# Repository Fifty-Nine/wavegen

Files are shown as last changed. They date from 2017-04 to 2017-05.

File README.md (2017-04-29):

Introduction
============

This is an implementation of a USB-controlled Analog Devices AD9837-based 
function generator that can generate sine, triangle and square waves up to 
around 200 kHz or so, 1 MHz if the output filtering capacitor is removed
(although the quantization of the ADC starts to become apparent around
500 kHz).

Fully assembled Rev. 2 board

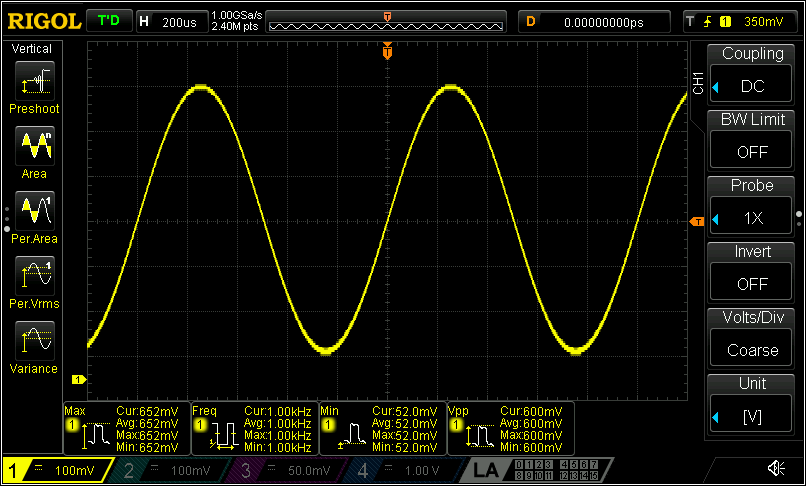
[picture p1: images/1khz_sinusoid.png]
Sample output


Connectors, Jumpers and Indicators
==================================

There are several off-board connectors, one jumper and three
LEDs.

| Reference | Purpose |
| --- | --- |
| J1 | Micro-B USB Connector |
| J2 | External clock input |
| J3 | Function generator output (0.6Vpp typical) |
| J4 | FTDI channel B breakout |
| TP1 | USB supply voltage (5V typical, 15V max) |
| TP2 | GND |
| TP3 | LD1117 output (3.3V nominal) |
| TP4 | Function generator output (0.6Vpp typical  |
| JP1 | Clock select jumper |
| D1 | LD1117 power indicator |
| D2 | Currently unused |
| D3 | Currently unused |

At some point I'll document the pinout for the J4 connector here.
Until then the pinout is available in the schematic.

Indicators D2 and D3 were originally intended as SPI TX/RX indicators, but
that was before I realized that the FT2232H only enables them for UART
communication (and also that the AD 9837 has no TX...). There's nothing
stopping the control software from using them for other purposes, although
the silkscreen on rev. 2 would be misleading.

Firmware
========

Because the design is based on the FTDI FT2232H, there's no firmware per se.
However, the control software looks for certain USB product and manufacturer
strings to differentiate the device from other FTDI devices. A template for
the FTDI 'FT_Prog' EEPROM programming software is provided in the `firmware/`
directory. The device should be programmed with this template before attempting
to use the control software.

Control Software
================

The control software is a work in progress, but the device can currently be
fully controlled via a provided software library. The library is written in
C++ and requires a compiler with C++11 support.

To build the library, you will need CMake and a suitable C++ compiler. On
linux, the build steps go something like this:

```
$ sudo apt-get install git build-essential cmake libftdi-dev
...
$ git clone git@github.com:Fifty-Nine/wavegen
...
$ cd wavegen/software
$ mkdir build
$ cd build
$ cmake ..
...
$ make
...
$ sudo make install
...
$
```

At this point, you can use the `wavegen-test` program to confirm that the device
is working. The test program initializes the device and repeatedly performs a
frequency sweep.

Future Work
===========

A GUI control interface would be nice to have. 

One major limitation of the current hardware is that it provides no output
amplitude control or amplification. At some point I would like to design
an amplification stage with automatic gain control. Rev 3 will allow
arbitrary waveform generation, so this will be mitigated somewhat.

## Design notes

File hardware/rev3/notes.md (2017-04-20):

Notes for a future rev3
=======================

- Stacking/nesting design.
- Replace VOUT capacitor with something much smaller to decrease attenuation at higher frequencies.
- ESD suppression on the USB lines.
- Shorten USB traces, try to get the impedance closer to the spec.
- Amplifier stage (w/AGC?)
- RCA jack?
- Microcontroller-based LCD UI?
- Multiple channels?
- ADC

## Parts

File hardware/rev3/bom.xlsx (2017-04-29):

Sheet: Sheet1
Id | Designator | Designation | Package | Quantity | Supplier and ref
1 | D1 | Green | LED_0805 | 1 | 350-2900-ND (https://www.digikey.com/products/en?keywords=350-2900-ND)
2 | J3;J5 | CONN_02X09 | Pin_Header_Straight_2x09_Pitch2.54mm | 2 | S2011EC-40-ND (https://www.digikey.com/products/en?keywords=S2011EC-40-ND)
3 | TP1 | VBUS | Test_Point_Keystone_5005-5009_Compact | 1 | 36-5009-ND (https://www.digikey.com/products/en?keywords=36-5009-ND)
4 | TP2 | +3.3V | Test_Point_Keystone_5005-5009_Compact | 1 | 36-5005-ND (https://www.digikey.com/products/en?keywords=36-5005-ND)
5 | TP3 | GND | Test_Point_Keystone_5005-5009_Compact | 1 | 36-5006-ND (https://www.digikey.com/products/en?keywords=36-5006-ND)
6 | U1 | LD1117S33TR | SOT-223 | 1 | 497-1242-1-ND (https://www.digikey.com/products/en/integrated-circuits-ics/pmic-voltage-regulators-linear/699?k=497-1242-1-ND)
7 | U2 | 93LCxxB | SOIC-8_3.9x4.9mm_Pitch1.27mm | 1 | 93LC46BT-I/SNCT-ND (https://www.digikey.com/products/en?keywords=93LC46BT-I%2FSNCT-ND)
8 | U3 | FT2232H | LQFP-64_10x10mm_Pitch0.5mm | 1 | 768-1024-1-ND (https://www.digikey.com/products/en?keywords=768-1024-1-ND)
9 | Y1 | 12MHz | Crystal_SMD_5032-2pin_5.0x3.2mm | 1 | 535-10634-1-ND (https://www.digikey.com/products/en?keywords=535-10634-1-ND)
10 | C1;C4;C6;C8-C15;C23-C25;C28;C30;C33;C35-C41;C44;C47 | 100n | C_0603_HandSoldering | 26 | 478-1239-1-ND (https://www.digikey.com/product-detail/en/avx-corporation/0603YC104KAT2A/478-1239-1-ND/564271)
11 | C2;C22;C29;C34;C42 | 10u | C_0603_HandSoldering | 5 | 478-8050-1-ND (https://www.digikey.com/product-detail/en/avx-corporation/0603ZD106MAT2A/478-8050-1-ND/3900666)
12 | C3;C5;C45 | 4.7u | C_0603_HandSoldering | 3 | 478-7943-1-ND (https://www.digikey.com/product-detail/en/avx-corporation/0603ZD475KAT2A/478-7943-1-ND/3881566)
13 | C7 | 3.3u | C_0603_HandSoldering | 1 | 490-6411-1-ND (https://www.digikey.com/product-detail/en/murata-electronics-north-america/GRM188R61A335KE15D/490-6411-1-ND/3845608)
14 | C16;C17 | 27p | C_0603_HandSoldering | 2 | 478-1168-1-ND (https://www.digikey.com/product-detail/en/avx-corporation/06035A270JAT2A/478-1168-1-ND/564200)
15 | C26;C32 | 0.8p | C_0603_HandSoldering | 2 | 478-6730-1-ND (https://www.digikey.com/product-detail/en/avx-corporation/ML03510R8AAT2A/478-6730-1-ND/2694244)
16 | C27;C31 | 2.8p | C_0603_HandSoldering | 2 | 478-3840-1-ND (https://www.digikey.com/product-detail/en/avx-corporation/06032U2R7BAT2A/478-3840-1-ND/1118502)
17 | C43;C46 | 1u | C_0603_HandSoldering | 2 | 478-5010-2-ND (https://www.digikey.com/product-detail/en/avx-corporation/0603YC105KAT2A/478-5010-2-ND/1888462)
18 | J2 | SMA | SMA_THT_Jack_Straight | 1 | A97594-ND (https://www.digikey.com/products/en?keywords=A97594-ND)
19 | J4;J6;J7 | SMA | Molex_SMA_Jack_Edge_Mount | 3 | WM5534-ND (https://www.digikey.com/product-detail/en/molex-llc/0732511150/WM5534-ND/1465156)
20 | L1;L2;L3;L4 | 800m | L_0603_HandSoldering | 4 | 490-5255-1-ND (https://www.digikey.com/product-detail/en/murata-electronics-north-america/BLM18KG221SN1D/490-5255-1-ND/1982778)
21 | R3;R4;R5 | 10k | R_0603_HandSoldering | 3 | P10KBZCT-ND (https://www.digikey.com/product-detail/en/panasonic-electronic-components/ERJ-PA3J103V/P10KBZCT-ND/5036237)
22 | R6 | 2.2k | R_0603_HandSoldering | 1 | P2.2KBZCT-ND (https://www.digikey.com/product-detail/en/panasonic-electronic-components/ERJ-PA3J222V/P2.2KBZCT-ND/5036284)
23 | R7;R13;R16;R17;R25;R29 | 4.7k | R_0603_HandSoldering | 6 | P4.7KBZCT-ND (https://www.digikey.com/product-detail/en/panasonic-electronic-components/ERJ-PA3J472V/P4.7KBZCT-ND/5036332)
24 | R8 | 12k | R_0603_HandSoldering | 1 | P12.0KHCT-ND (https://www.digikey.com/product-detail/en/panasonic-electronic-components/ERJ-3EKF1202V/P12.0KHCT-ND/1746728)
25 | R11 | 8.25k | R_0603_HandSoldering | 1 | P8.25KDBCT-ND (https://www.digikey.com/products/en/resistors/chip-resistor-surface-mount/52?k=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)
26 | R2;R12;R27 | 510 | R_0603_HandSoldering | 3 | P510BYCT-ND (https://www.digikey.com/products/en/resistors/chip-resistor-surface-mount/52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)
27 | R14;R23 | 1.5k | R_0603_HandSoldering | 2 | P1.5KBYCT-ND (https://www.digikey.com/product-detail/en/panasonic-electronic-components/ERJ-PA3F1501V/P1.5KBYCT-ND/5036135)
28 | R15;R19;R20;R22;R24 | 100 | R_0603_HandSoldering | 5 | P100BYCT-ND (https://www.digikey.com/product-detail/en/panasonic-electronic-components/ERJ-PA3F1000V/P100BYCT-ND/5036113)
29 | R18;R21 | 1k | R_0603_HandSoldering | 2 | P1.0KBYCT-ND (https://www.digikey.com/product-detail/en/panasonic-electronic-components/ERJ-PA3F1001V/P1.0KBYCT-ND/5036114)
30 | R26;R28 | 36k | R_0603_HandSoldering | 2 | P20459CT-ND (https://www.digikey.com/product-detail/en/panasonic-electronic-components/ERJ-PB3D3602V/P20459CT-ND/6214714)
31 | TP4 | TRIGGER | Test_Point_Keystone_5005-5009_Compact | 1 | 36-5122-ND (https://www.digikey.com/product-detail/en/keystone-electronics/5122/36-5122-ND/2170325)
32 | TP5 | VOUT+ | Test_Point_Keystone_5005-5009_Compact | 1 | 36-5005-ND (https://www.digikey.com/product-detail/en/keystone-electronics/5005/36-5005-ND/255329)
33 | TP6 | VOUT- | Test_Point_Keystone_5005-5009_Compact | 1 | 36-5007-ND (https://www.digikey.com/product-detail/en/keystone-electronics/5007/36-5007-ND/255331)
34 | TP7 | VOUT | Test_Point_Keystone_5005-5009_Compact | 1 | 36-5121-ND (https://www.digikey.com/product-detail/en/keystone-electronics/5121/36-5121-ND/2170324)
35 | U4 | LTC6409 | LTC6409-UDB | 1 | LTC6409CUDB#TRMPBFCT-ND (https://www.digikey.com/product-detail/en/linear-technology/LTC6409CUDB-TRMPBF/LTC6409CUDB-TRMPBFCT-ND/2404678)
36 | U5 | LTC6269 | LTC6269-10DFN | 1 | LTC6269HDD#PBF-ND (https://www.digikey.com/products/en/integrated-circuits-ics/linear-amplifiers-instrumentation-op-amps-buffer-amps/687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)
37 | U6 | AD9102 | AD9102-10LFCSP | 1 | AD9102BCPZ-ND (https://www.digikey.com/product-detail/en/analog-devices-inc/AD9102BCPZ/AD9102BCPZ-ND/3874219)
38 | X1 | DSC1123 | 3225XO | 1 | 576-4649-ND (https://www.digikey.com/products/en/crystals-oscillators-resonators/oscillators/172?k=dsc1123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)
39 | R30 | 18k | R_0603_HandSoldering | 1 | P20424CT-ND (https://www.digikey.com/product-detail/en/panasonic-electronic-components/ERJ-PB3D1802V/P20424CT-ND/6214679)
40 | J1 | USB_B | USB_Micro-B-circular | 1 | 609-4618-1-ND (https://www.digikey.com/product-detail/en/amphenol-fci/10118194-0001LF/609-4618-1-ND/2785382)
41 | JP1 | USB_PWR | Pin_Header_Straight_1x02_Pitch2.54mm | 1
42 | C18;C19;C20;C21 | DNP | C_0603_HandSoldering | 4
43 | R1;R9;R10 | DNP | R_0603_HandSoldering | 3
 |  |  |  | 97

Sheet: Sheet2
Quantity | Supplier and ref | Designator
1 | 350-2900-ND | D1
2 | S2011EC-40-ND | J3;J5
1 | 36-5009-ND | TP1
1 | 36-5005-ND | TP2
1 | 36-5006-ND | TP3
1 | 497-1242-1-ND | U1
1 | 93LC46BT-I/SNCT-ND | U2
1 | 768-1024-1-ND | U3
1 | 535-10634-1-ND | Y1
26 | 478-1239-1-ND | C1;C4;C6;C8-C15;C23-C25;C28;C30;C33;C35-C41;C44;C47
5 | 478-8050-1-ND | C2;C22;C29;C34;C42
3 | 478-7943-1-ND | C3;C5;C45
1 | 490-6411-1-ND | C7
2 | 478-1168-1-ND | C16;C17
2 | 478-6730-1-ND | C26;C32
2 | 478-3840-1-ND | C27;C31
2 | 478-5010-2-ND | C43;C46
1 | A97594-ND | J2
3 | WM5534-ND | J4;J6;J7
4 | 490-5255-1-ND | L1;L2;L3;L4
3 | P10KBZCT-ND | R3;R4;R5
1 | P2.2KBZCT-ND | R6
6 | P4.7KBZCT-ND | R7;R13;R16;R17;R25;R29
1 | P12.0KHCT-ND | R8
1 | P8.25KDBCT-ND | R11
3 | P510BYCT-ND | R2;R12;R27
2 | P1.5KBYCT-ND | R14;R23
5 | P100BYCT-ND | R15;R19;R20;R22;R24
2 | P1.0KBYCT-ND | R18;R21
2 | P20459CT-ND | R26;R28
1 | 36-5122-ND | TP4
1 | 36-5005-ND | TP5
1 | 36-5007-ND | TP6
1 | 36-5121-ND | TP7
1 | LTC6409CUDB#TRMPBFCT-ND | U4
1 | LTC6269HDD#PBF-ND | U5
1 | AD9102BCPZ-ND | U6
1 | 576-4649-ND | X1
1 | P20424CT-ND | R30
1 | 609-4618-1-ND | J1
1 | 0 | JP1
4 | 0 | C18;C19;C20;C21
3 | 0 | R1;R9;R10

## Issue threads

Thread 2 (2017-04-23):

Find some way to limit square wave output power

Fifty-Nine, 2017-04-23:
When outputting square waves, the AD9837 produces a signal at 3.3Vpp (~17 dBm with 50 ohm impedance), but triangle and sinusoids are around 600 mV (~0 dBm). Ideally the signal levels for square waves would be around the same power (or perhaps voltage levels) as the others.

Fifty-Nine, 2017-05-02:
On further reflection, I don't think this is that critical of an issue. It's not ideal, but without a hardware change I don't know that there's any way to fix it, and in most applications it won't be a problem.

Closed 2017-05-02.

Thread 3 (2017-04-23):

Missing ground connection on oscillator Y1

Fifty-Nine, 2017-04-23:
The decoupling caps on Y1 (12 MHz oscillator for the FTDI chip) are missing a connection to ground.

This can be worked around by using a small jumper to connect the capacitors' ground pad to the nearby bypass capacitors C19 and C20.

This is fixed in rev2.

Closed 2017-04-25.

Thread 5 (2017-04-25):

Python bindings should implement `__del__`

Fifty-Nine, 2017-04-25:
Currently when a `pywavegen.device` instance is destroyed, we don't actually delete the global instance. We should add a binding for `__del__` that calls 'reset' on the global shared pointer. We should also double check that this actually has the intended result of releasing the underlying resources.

Closed 2017-04-26.

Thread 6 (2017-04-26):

Add differential to single-ended stage to output amp

Fifty-Nine, 2017-04-26:
I've added another stage to the output amplifier to convert the differential signal into a single ended one, but haven't added it to the actual schematic yet.

Because the amplifiers are a little power hungry, I think we'll need to make use of their shutdown pins, which isn't reflected on the LTSpice schematic.

Closed 2017-05-02.

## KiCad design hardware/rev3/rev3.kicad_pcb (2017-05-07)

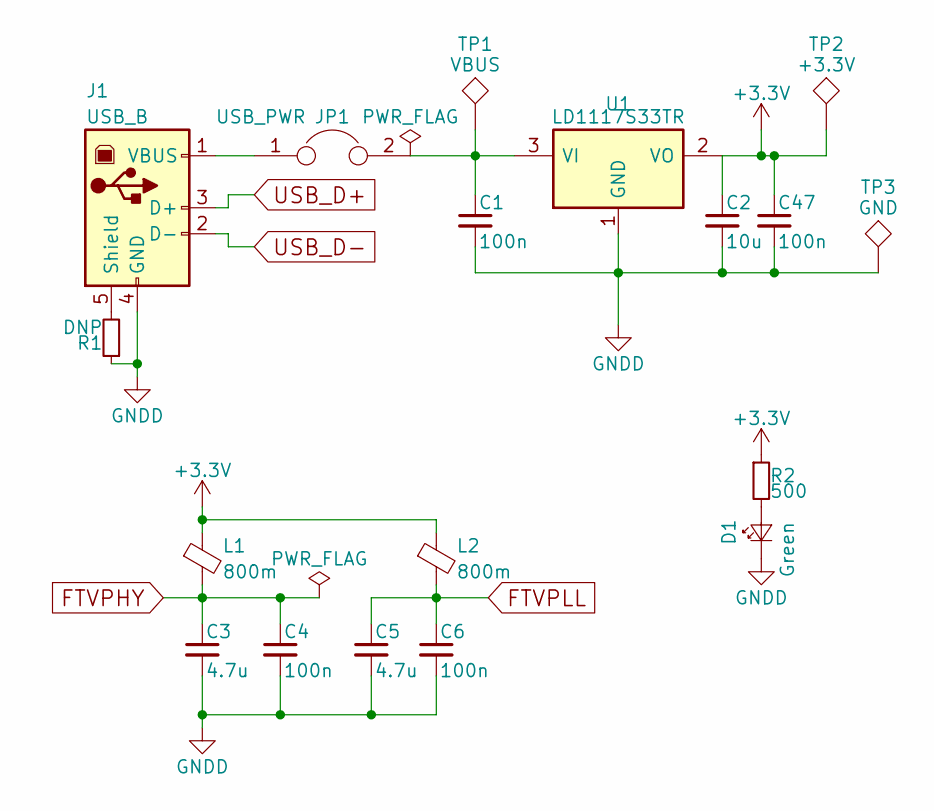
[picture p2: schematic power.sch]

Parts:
C1, C4, C6, C47: 100n; C_0603_HandSoldering; DigiKey 478-1395-1-ND
C2: 10u; C_0603_HandSoldering; DigiKey 478-10568-1-ND
C3, C5: 4.7u; C_0603_HandSoldering; DigiKey 478-1415-1-ND
D1: Green; LED_0805; DigiKey 350-2900-ND
J1: USB_B; USB_Micro-B-circular; DigiKey 609-4618-1-ND
JP1: USB_PWR; Pin_Header_Straight_1x02_Pitch2.54mm
L1, L2: 800m; L_0603_HandSoldering; DigiKey 490-1054-1-ND
R1: DNP; R_0603_HandSoldering; DigiKey DNP
R2: 500; R_0603_HandSoldering; DigiKey P470ADCT-ND
TP1: VBUS; Test_Point_Keystone_5005-5009_Compact; DigiKey 36-5009-ND
TP2: +3.3V; Test_Point_Keystone_5005-5009_Compact; DigiKey 36-5005-ND
TP3: GND; Test_Point_Keystone_5005-5009_Compact; DigiKey 36-5006-ND
U1: LD1117S33TR; SOT-223; DigiKey 497-1242-1-ND

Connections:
+3V3: C2.1, C47.1, L1.1, L2.1, R2.1, TP2.1, U1.2 (VO); also elsewhere on the board
FTVPHY: C3.1, C4.1, L1.2; also elsewhere on the board
FTVPLL: C5.1, C6.1, L2.2; also elsewhere on the board
GNDA: C1.2, C2.2, C3.2, C4.2, C5.2, C6.2, C47.2, D1.1 (K), J1.4 (GND), R1.1, TP3.1, U1.1 (GND); also elsewhere on the board
unnamed: C1.1, JP1.2, TP1.1, U1.3 (VI)
unnamed: D1.2 (A), R2.2
unnamed: J1.1 (VBUS), JP1.1
unnamed: J1.5 (Shield), R1.2
USB_D+: J1.3 (D+); also elsewhere on the board
USB_D-: J1.2 (D-); also elsewhere on the board

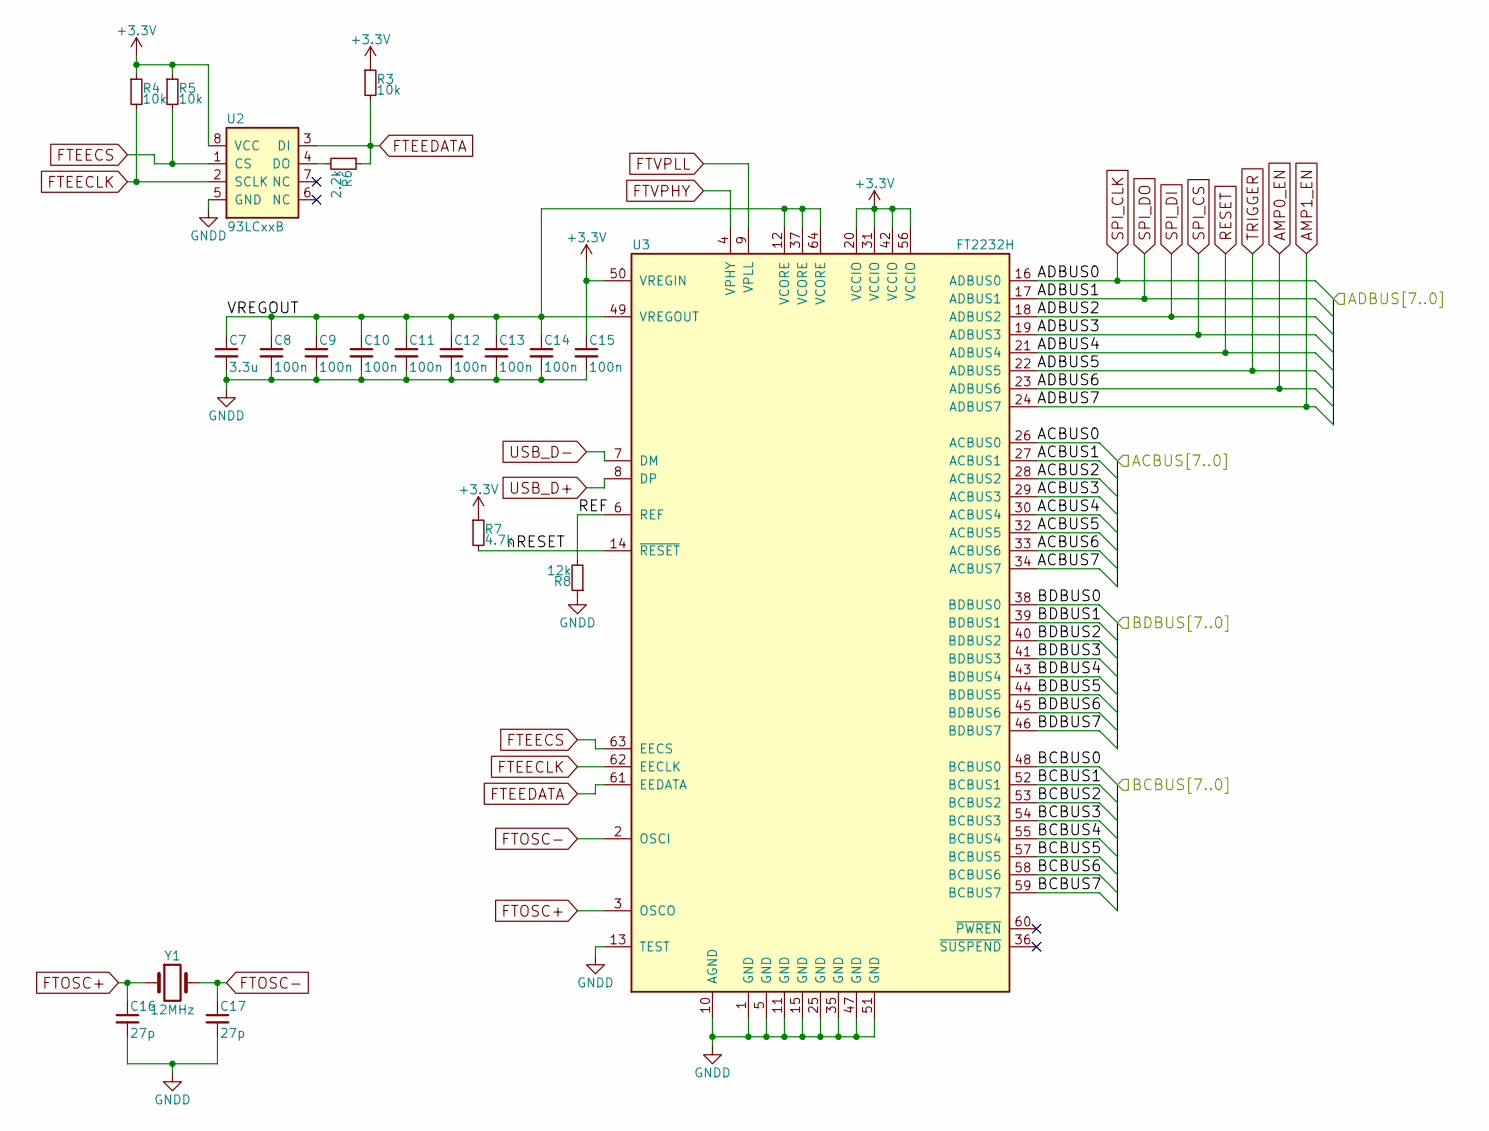
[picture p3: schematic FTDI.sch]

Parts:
C7: 3.3u; C_0805; DigiKey 478-1414-1-ND
C8, C9, C10, C11, C12, C13, C14, C15: 100n; C_0805; DigiKey 478-1395-1-ND
C16, C17: 27p; C_0805; DigiKey 478-10518-1-ND
R3, R4, R5: 10k; R_0805; DigiKey P10KADCT-ND
R6: 2.2k; R_0805; DigiKey P2.2KADCT-ND
R7: 4.7k; R_0805; DigiKey P1.0KADCT-ND
R8: 12k; R_0805; DigiKey P12KADCT-ND
U2: 93LCxxB; SOIC-8_3.9x4.9mm_Pitch1.27mm; DigiKey 93LC46B/SN-ND
U3: FT2232H; LQFP-64_10x10mm_Pitch0.5mm
Y1: 12MHz; Crystal_SMD_5032-2pin_5.0x3.2mm; DigiKey 535-10634-1-ND

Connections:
+3V3: C15.1, R3.1, R4.1, R5.1, R7.1, U2.8 (VCC), U3.20 (VCCIO), U3.31 (VCCIO), U3.42 (VCCIO), U3.50 (VREGIN), U3.56 (VCCIO); also elsewhere on the board
/Connectors/ACBUS0: U3.26 (ACBUS0); also elsewhere on the board
/Connectors/ACBUS1: U3.27 (ACBUS1); also elsewhere on the board
/Connectors/ACBUS2: U3.28 (ACBUS2); also elsewhere on the board
/Connectors/ACBUS3: U3.29 (ACBUS3); also elsewhere on the board
/Connectors/ACBUS4: U3.30 (ACBUS4); also elsewhere on the board
/Connectors/ACBUS5: U3.32 (ACBUS5); also elsewhere on the board
/Connectors/ACBUS6: U3.33 (ACBUS6); also elsewhere on the board
/Connectors/ACBUS7: U3.34 (ACBUS7); also elsewhere on the board
/Connectors/BCBUS0: U3.48 (BCBUS0); also elsewhere on the board
/Connectors/BCBUS1: U3.52 (BCBUS1); also elsewhere on the board
/Connectors/BCBUS2: U3.53 (BCBUS2); also elsewhere on the board
/Connectors/BCBUS3: U3.54 (BCBUS3); also elsewhere on the board
/Connectors/BCBUS4: U3.55 (BCBUS4); also elsewhere on the board
/Connectors/BCBUS5: U3.57 (BCBUS5); also elsewhere on the board
/Connectors/BCBUS6: U3.58 (BCBUS6); also elsewhere on the board
/Connectors/BCBUS7: U3.59 (BCBUS7); also elsewhere on the board
/Connectors/BDBUS0: U3.38 (BDBUS0); also elsewhere on the board
/Connectors/BDBUS1: U3.39 (BDBUS1); also elsewhere on the board
/Connectors/BDBUS2: U3.40 (BDBUS2); also elsewhere on the board
/Connectors/BDBUS3: U3.41 (BDBUS3); also elsewhere on the board
/Connectors/BDBUS4: U3.43 (BDBUS4); also elsewhere on the board
/Connectors/BDBUS5: U3.44 (BDBUS5); also elsewhere on the board
/Connectors/BDBUS6: U3.45 (BDBUS6); also elsewhere on the board
/Connectors/BDBUS7: U3.46 (BDBUS7); also elsewhere on the board
/FTDI/REF: R8.2, U3.6 (REF)
/FTDI/VREGOUT: C7.1, C8.1, C9.1, C10.1, C11.1, C12.1, C13.1, C14.1, U3.12 (VCORE), U3.37 (VCORE), U3.49 (VREGOUT), U3.64 (VCORE)
/FTDI/nRESET: R7.2, U3.14 (~RESET)
AMP0_EN: U3.23 (ADBUS6); also elsewhere on the board
AMP1_EN: U3.24 (ADBUS7); also elsewhere on the board
FTEECLK: R4.2, U2.2 (SCLK), U3.62 (EECLK)
FTEECS: R5.2, U2.1 (CS), U3.63 (EECS)
FTEEDATA: R3.2, R6.1, U2.3 (DI), U3.61 (EEDATA)
FTOSC+: C16.1, U3.3 (OSCO), Y1.1
FTOSC-: C17.1, U3.2 (OSCI), Y1.2
FTVPHY: U3.4 (VPHY); also elsewhere on the board
FTVPLL: U3.9 (VPLL); also elsewhere on the board
GNDA: C7.2, C8.2, C9.2, C10.2, C11.2, C12.2, C13.2, C14.2, C15.2, C16.2, C17.2, R8.1, U2.5 (GND), U3.1 (GND), U3.5 (GND), U3.10 (AGND), U3.11 (GND), U3.13 (TEST), U3.15 (GND), U3.25 (GND), U3.35 (GND), U3.47 (GND), U3.51 (GND); also elsewhere on the board
unnamed: R6.2, U2.4 (DO)
RESET: U3.21 (ADBUS4); also elsewhere on the board
SPI_CLK: U3.16 (ADBUS0); also elsewhere on the board
SPI_CS: U3.19 (ADBUS3); also elsewhere on the board
SPI_DI: U3.18 (ADBUS2); also elsewhere on the board
SPI_DO: U3.17 (ADBUS1); also elsewhere on the board
TRIGGER: U3.22 (ADBUS5); also elsewhere on the board
USB_D+: U3.8 (DP); also elsewhere on the board
USB_D-: U3.7 (DM); also elsewhere on the board

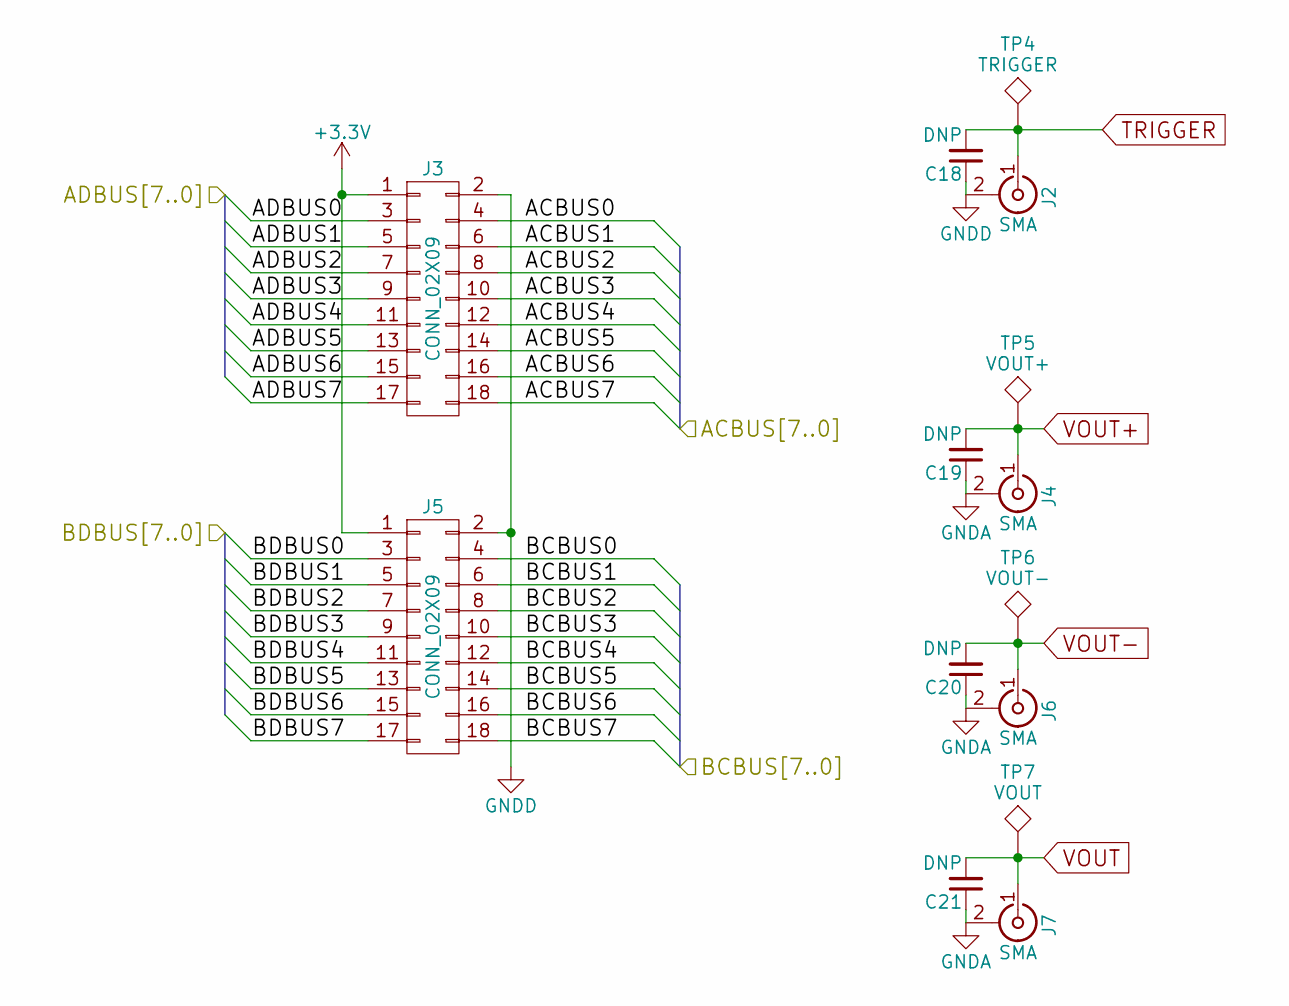
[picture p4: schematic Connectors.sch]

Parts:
C18, C19, C20, C21: DNP; C_0603_HandSoldering
J2: SMA; SMA_THT_Jack_Straight
J3, J5: CONN_02X09; Pin_Header_Straight_2x09_Pitch2.54mm; DigiKey S2011EC-40-ND
J4, J6, J7: SMA; Molex_SMA_Jack_Edge_Mount
TP4: TRIGGER; Test_Point_Keystone_5005-5009_Compact
TP5: VOUT+; Test_Point_Keystone_5005-5009_Compact
TP6: VOUT-; Test_Point_Keystone_5005-5009_Compact
TP7: VOUT; Test_Point_Keystone_5005-5009_Compact

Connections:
+3V3: J3.1, J5.1; also elsewhere on the board
/Connectors/ACBUS0: J3.4; also elsewhere on the board
/Connectors/ACBUS1: J3.6; also elsewhere on the board
/Connectors/ACBUS2: J3.8; also elsewhere on the board
/Connectors/ACBUS3: J3.10; also elsewhere on the board
/Connectors/ACBUS4: J3.12; also elsewhere on the board
/Connectors/ACBUS5: J3.14; also elsewhere on the board
/Connectors/ACBUS6: J3.16; also elsewhere on the board
/Connectors/ACBUS7: J3.18; also elsewhere on the board
/Connectors/BCBUS0: J5.4; also elsewhere on the board
/Connectors/BCBUS1: J5.6; also elsewhere on the board
/Connectors/BCBUS2: J5.8; also elsewhere on the board
/Connectors/BCBUS3: J5.10; also elsewhere on the board
/Connectors/BCBUS4: J5.12; also elsewhere on the board
/Connectors/BCBUS5: J5.14; also elsewhere on the board
/Connectors/BCBUS6: J5.16; also elsewhere on the board
/Connectors/BCBUS7: J5.18; also elsewhere on the board
/Connectors/BDBUS0: J5.3; also elsewhere on the board
/Connectors/BDBUS1: J5.5; also elsewhere on the board
/Connectors/BDBUS2: J5.7; also elsewhere on the board
/Connectors/BDBUS3: J5.9; also elsewhere on the board
/Connectors/BDBUS4: J5.11; also elsewhere on the board
/Connectors/BDBUS5: J5.13; also elsewhere on the board
/Connectors/BDBUS6: J5.15; also elsewhere on the board
/Connectors/BDBUS7: J5.17; also elsewhere on the board
AMP0_EN: J3.15; also elsewhere on the board
AMP1_EN: J3.17; also elsewhere on the board
GNDA: C18.1, C19.1, C20.1, C21.1, J2.2 (Ext), J3.2, J4.2 (Ext), J5.2, J6.2 (Ext), J7.2 (Ext); also elsewhere on the board
RESET: J3.11; also elsewhere on the board
SPI_CLK: J3.3; also elsewhere on the board
SPI_CS: J3.9; also elsewhere on the board
SPI_DI: J3.7; also elsewhere on the board
SPI_DO: J3.5; also elsewhere on the board
TRIGGER: C18.2, J2.1 (In), J3.13, TP4.1; also elsewhere on the board
VOUT: C21.2, J7.1 (In), TP7.1; also elsewhere on the board
VOUT+: C19.2, J4.1 (In), TP5.1; also elsewhere on the board
VOUT-: C20.2, J6.1 (In), TP6.1; also elsewhere on the board

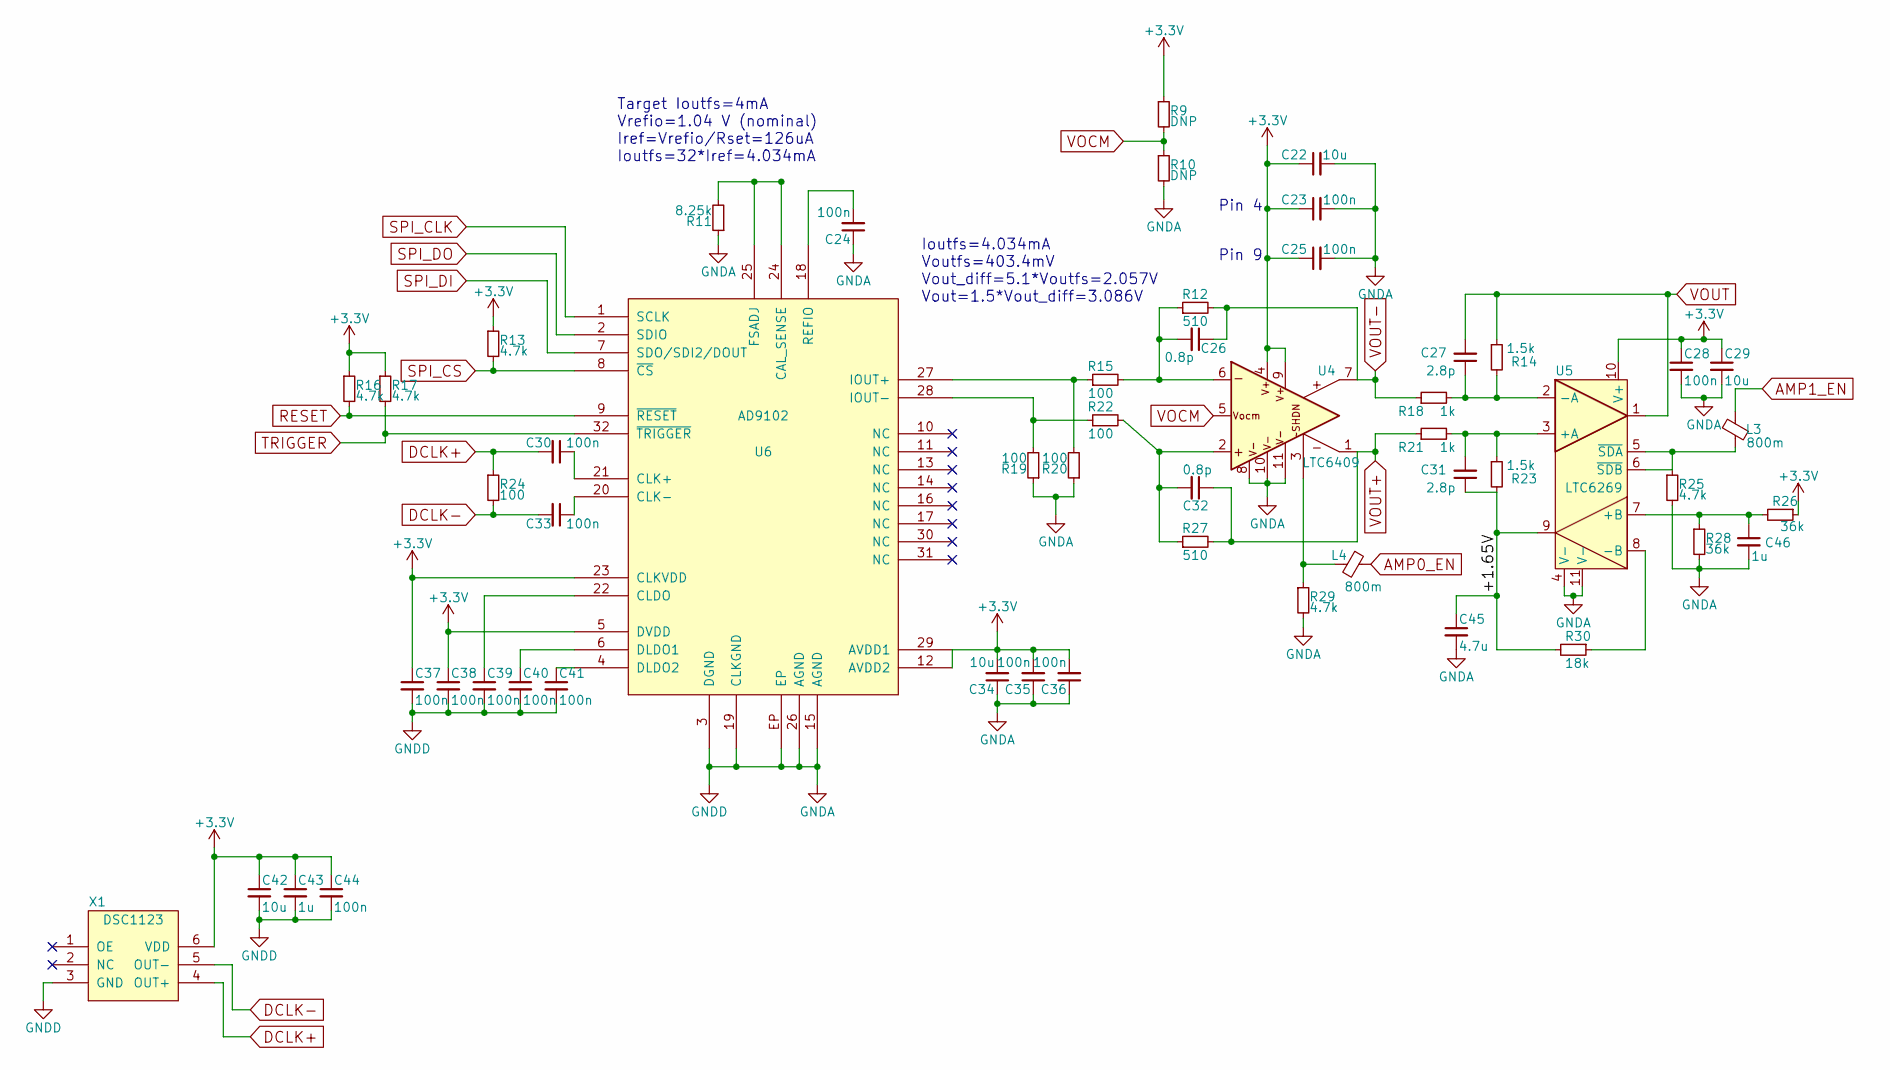
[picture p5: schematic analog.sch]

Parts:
C22, C29, C34, C42: 10u; C_0603_HandSoldering
C23, C24, C25, C28, C30, C33, C35, C36, C37, C38, C39, C40, C41, C44: 100n; C_0603_HandSoldering
C26, C32: 0.8p; C_0603_HandSoldering
C27, C31: 2.8p; C_0603_HandSoldering
C43, C46: 1u; C_0603_HandSoldering
C45: 4.7u; C_0603_HandSoldering
L3, L4: 800m; L_0603_HandSoldering
R9, R10: DNP; R_0603_HandSoldering
R11: 8.25k; R_0603_HandSoldering
R12, R27: 510; R_0603_HandSoldering
R13, R16, R17, R25, R29: 4.7k; R_0603_HandSoldering
R14, R23: 1.5k; R_0603_HandSoldering
R15, R19, R20, R22, R24: 100; R_0603_HandSoldering
R18, R21: 1k; R_0603_HandSoldering
R26, R28: 36k; R_0603_HandSoldering
R30: 18k; R_0603_HandSoldering
U4: LTC6409; LTC6409-UDB
U5: LTC6269; LTC6269-10DFN
U6: AD9102; AD9102-10LFCSP; DigiKey AD9102BCPZ-ND
X1: DSC1123; 7050XO; DigiKey 576-4642-ND

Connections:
+3V3: C22.1, C23.1, C25.1, C28.1, C29.1, C34.2, C35.2, C36.2, C37.1, C38.1, C42.1, C43.1, C44.1, R9.1, R13.1, R16.1, R17.1, R26.1, U4.4, U4.9, U5.10 (V+), U6.5 (DVDD), U6.12 (AVDD2), U6.23 (CLKVDD), U6.29 (AVDD1), X1.6 (VDD); also elsewhere on the board
/Analog/+1.65V: C31.1, C45.1, R23.2, R30.2, U5.9
AMP0_EN: L4.1; also elsewhere on the board
AMP1_EN: L3.2; also elsewhere on the board
DCLK+: C30.2, R24.1, X1.4 (OUT+)
DCLK-: C33.2, R24.2, X1.5 (OUT-)
GNDA: C22.2, C23.2, C24.1, C25.2, C28.2, C29.2, C34.1, C35.1, C36.1, C37.2, C38.2, C39.2, C40.2, C41.2, C42.2, C43.2, C44.2, C45.2, C46.2, R10.2, R11.1, R19.1, R20.1, R25.2, R28.2, R29.2, U4.8, U4.10, U4.11, U5.4 (V-), U5.11 (V-), U6.3 (DGND), U6.15 (AGND), U6.19 (CLKGND), U6.26 (AGND), U6.EP, X1.3 (GND); also elsewhere on the board
unnamed: C24.2, U6.18 (REFIO)
unnamed: C26.2, R12.1, R15.2, U4.6
unnamed: C27.1, R14.2, R18.2, U5.2 (-A)
unnamed: C30.1, U6.21 (CLK+)
unnamed: C31.2, R21.2, R23.1, U5.3 (+A)
unnamed: C32.2, R22.2, R27.1, U4.2
unnamed: C33.1, U6.20 (CLK-)
unnamed: C39.1, U6.22 (CLDO)
unnamed: C40.1, U6.6 (DLDO1)
unnamed: C41.1, U6.4 (DLDO2)
unnamed: C46.1, R26.2, R28.1, U5.7 (+B)
unnamed: L3.1, R25.1, U5.5 (~SDA), U5.6 (~SDB)
unnamed: L4.2, R29.1, U4.3
unnamed: R11.2, U6.24 (CAL_SENSE), U6.25 (FSADJ)
unnamed: R15.1, R20.2, U6.27 (IOUT+)
unnamed: R19.2, R22.1, U6.28 (IOUT-)
unnamed: R30.1, U5.8 (-B)
RESET: R16.2, U6.9 (~RESET); also elsewhere on the board
SPI_CLK: U6.1 (SCLK); also elsewhere on the board
SPI_CS: R13.2, U6.8 (~CS); also elsewhere on the board
SPI_DI: U6.7 (SDO/SDI2/DOUT); also elsewhere on the board
SPI_DO: U6.2 (SDIO); also elsewhere on the board
TRIGGER: R17.2, U6.32 (~TRIGGER); also elsewhere on the board
VOCM: R9.2, R10.1, U4.5
VOUT: C27.2, R14.1, U5.1; also elsewhere on the board
VOUT+: C32.1, R21.1, R27.2, U4.1; also elsewhere on the board
VOUT-: C26.1, R12.2, R18.1, U4.7; also elsewhere on the board

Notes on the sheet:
Pin 4
Pin 9
Target Ioutfs=4mA Vrefio=1.04 V (nominal) Iref=Vrefio/Rset=126uA Ioutfs=32*Iref=4.034mA
Ioutfs=4.034mA Voutfs=403.4mV Vout_diff=5.1*Voutfs=2.057V Vout=1.5*Vout_diff=3.086V

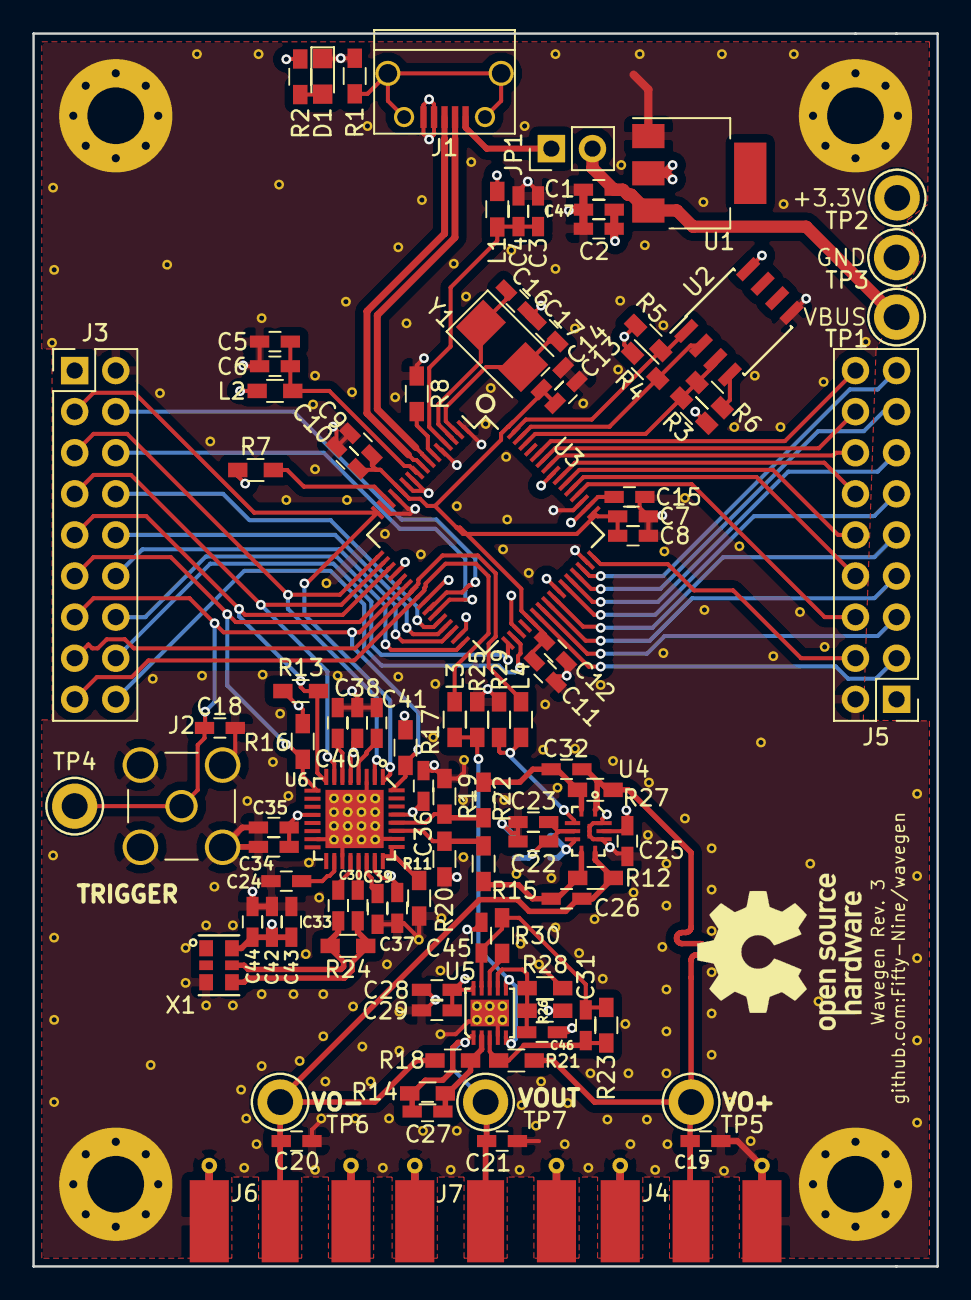
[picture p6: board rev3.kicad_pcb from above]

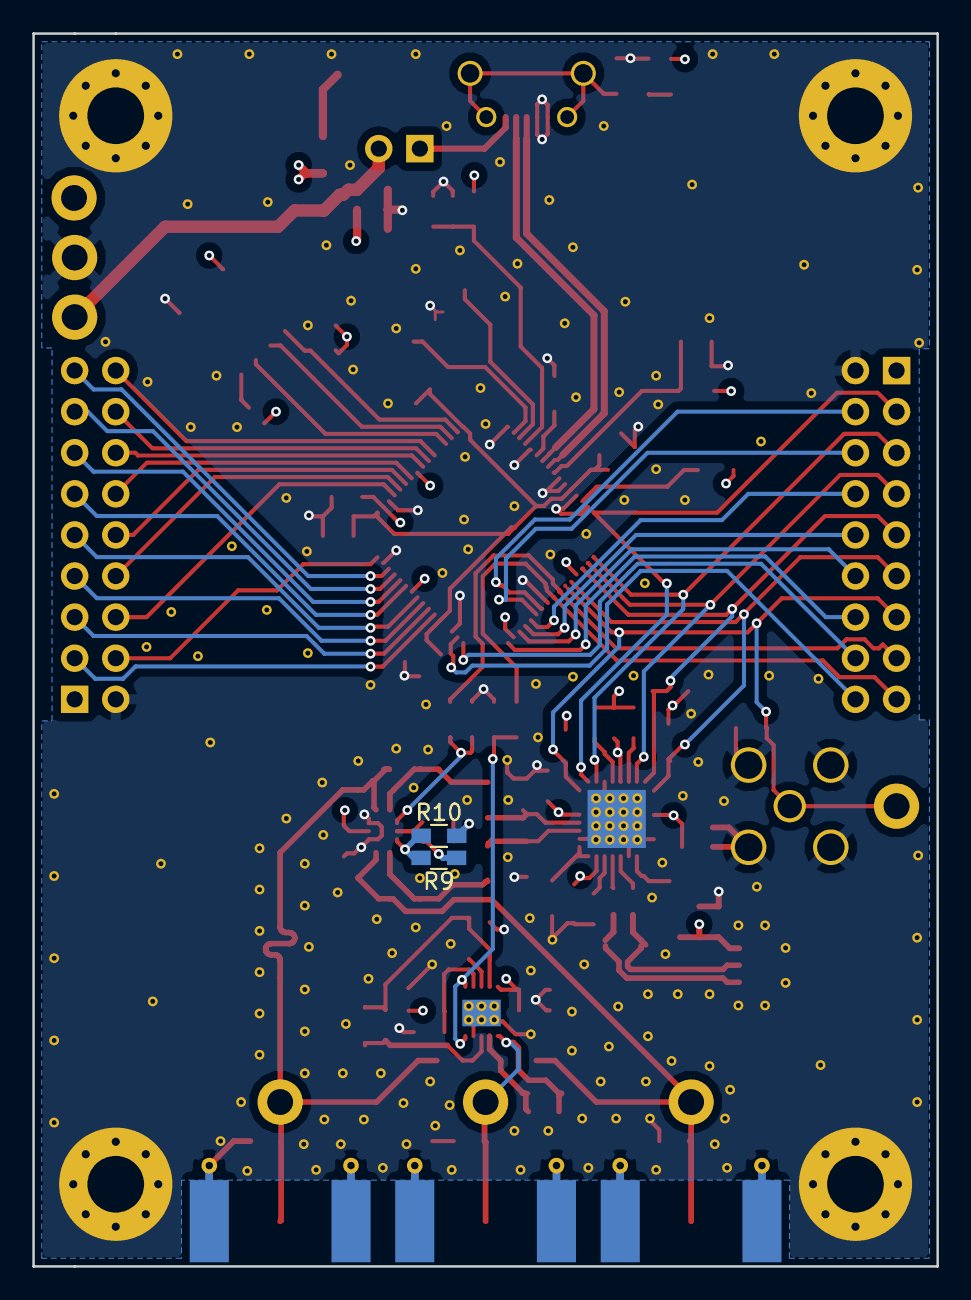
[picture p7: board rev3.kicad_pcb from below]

Board: 4 copper layers, 55.9 x 76.2 mm, 105 parts (2 on the bottom side), 75 nets.

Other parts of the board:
 C19: DNP; C_0603_HandSoldering

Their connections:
GNDA: C19.1; also elsewhere on the board
VOUT+: C19.2; also elsewhere on the board

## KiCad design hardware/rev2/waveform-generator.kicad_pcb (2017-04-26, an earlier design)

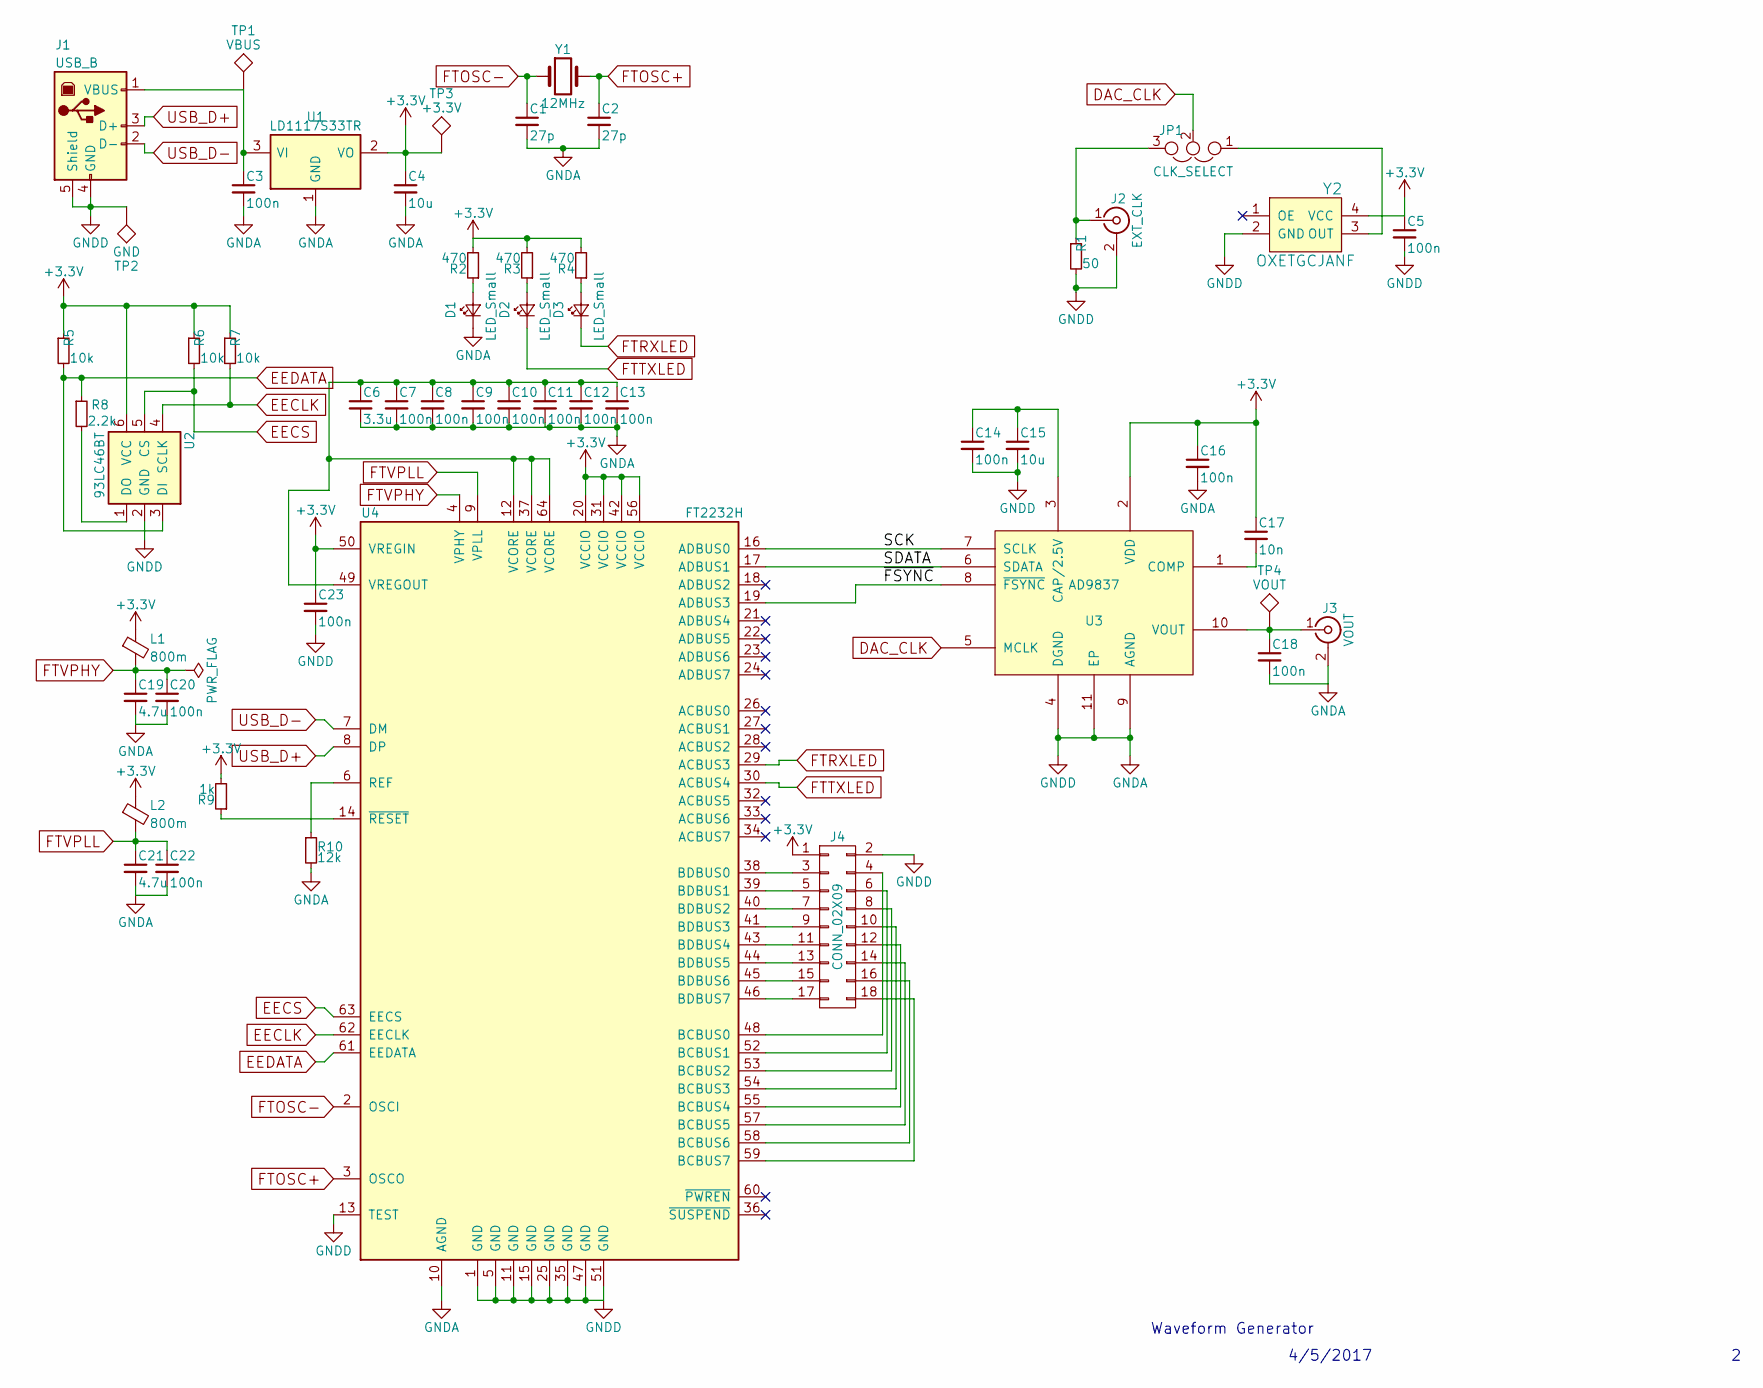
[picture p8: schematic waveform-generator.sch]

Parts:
C1, C2: 27p; C_0805_HandSoldering
C3, C5, C7, C8, C9, C10, C11, C12, C13, C14, C16, C18, C20, C22, C23: 100n; C_0805_HandSoldering
C4, C15: 10u; C_0805_HandSoldering
C6: 3.3u; C_0805_HandSoldering
C17: 10n; C_0805_HandSoldering
C19, C21: 4.7u; C_0805_HandSoldering
D1, D2, D3: LED_Small; LED_0805
J1: USB_B; USB_Micro-B
J2: EXT_CLK; SMA_THT_Jack_Straight
J3: VOUT; SMA_THT_Jack_Straight
J4: CONN_02X09; Pin_Header_Straight_2x09_Pitch2.54mm
JP1: CLK_SELECT; Pin_Header_Straight_1x03_Pitch2.54mm
L1, L2: 800m; L_0805_HandSoldering
R1: 50; R_0603_HandSoldering
R2, R3, R4: 470; R_0805_HandSoldering
R5, R6, R7: 10k; R_0805_HandSoldering
R8: 2.2k; R_0805_HandSoldering
R9: 1k; R_0805_HandSoldering
R10: 12k; R_0805_HandSoldering
TP1: VBUS; Test_Point_Keystone_5005-5009_Compact
TP2: GND; Test_Point_Keystone_5005-5009_Compact
TP3: +3.3V; Test_Point_Keystone_5005-5009_Compact
TP4: VOUT; Test_Point_Keystone_5005-5009_Compact
U1: LD1117S33TR; SOT-223
U2: 93LC46BT; SOT-23-6_Handsoldering
U3: AD9837
U4: FT2232H; LQFP-64_10x10mm_Pitch0.5mm
Y1: 12MHz; Crystal_SMD_5032-2pin_5.0x3.2mm_HandSoldering
Y2: OXETGCJANF; Oscillator_SMD_Abracon_ASE-4pin_3.2x2.5mm_HandSoldering

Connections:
+3V3: C4.1, C5.1, C16.1, C17.1, C23.1, J4.1, L1.1, L2.1, R2.2, R3.2, R4.2, R5.1, R6.1, R7.1, R9.2, TP3.1, U1.2 (VO), U2.6 (VCC), U3.2 (VDD), U4.20 (VCCIO), U4.31 (VCCIO), U4.42 (VCCIO), U4.50 (VREGIN), U4.56 (VCCIO), Y2.4 (VCC)
/SCK: U3.7 (SCLK), U4.16 (ADBUS0)
/SDATA: U3.6 (SDATA), U4.17 (ADBUS1)
/~FSYNC: U3.8 (~FSYNC), U4.19 (ADBUS3)
DAC_CLK: JP1.2, U3.5 (MCLK)
EECLK: R7.2, U2.4 (SCLK), U4.62 (EECLK)
EECS: R6.2, U2.5 (CS), U4.63 (EECS)
EEDATA: R5.2, R8.1, U2.3 (DI), U4.61 (EEDATA)
FTOSC+: C2.1, U4.3 (OSCO), Y1.2
FTOSC-: C1.1, U4.2 (OSCI), Y1.1
FTRXLED: D3.1 (K), U4.29 (ACBUS3)
FTTXLED: D2.1 (K), U4.30 (ACBUS4)
FTVPHY: C19.1, C20.1, L1.2, U4.4 (VPHY)
FTVPLL: C21.1, C22.1, L2.2, U4.9 (VPLL)
GNDA: C1.2, C2.2, C3.2, C4.2, C5.2, C6.2, C7.2, C8.2, C9.2, C10.2, C11.2, C12.2, C13.2, C14.2, C15.2, C16.2, C18.2, C19.2, C20.2, C21.2, C22.2, C23.2, D1.1 (K), J1.4 (GND), J1.5 (Shield), J2.2 (Ext), J3.2 (Ext), J4.2, R1.2, R10.2, TP2.1, U1.1 (GND), U2.2 (GND), U3.4 (DGND), U3.9 (AGND), U3.11 (EP), U4.1 (GND), U4.5 (GND), U4.10 (AGND), U4.11 (GND), U4.13 (TEST), U4.15 (GND), U4.25 (GND), U4.35 (GND), U4.47 (GND), U4.51 (GND), Y2.2 (GND)
unnamed: C3.1, J1.1 (VBUS), TP1.1, U1.3 (VI)
unnamed: C6.1, C7.1, C8.1, C9.1, C10.1, C11.1, C12.1, C13.1, U4.12 (VCORE), U4.37 (VCORE), U4.49 (VREGOUT), U4.64 (VCORE)
unnamed: C14.1, C15.1, U3.3 (CAP/2.5V)
unnamed: C17.2, U3.1 (COMP)
unnamed: C18.1, J3.1 (In), TP4.1, U3.10 (VOUT)
unnamed: D1.2 (A), R2.1
unnamed: D2.2 (A), R3.1
unnamed: D3.2 (A), R4.1
unnamed: J2.1 (In), JP1.3, R1.1
unnamed: J4.3, U4.38 (BDBUS0)
unnamed: J4.4, U4.48 (BCBUS0)
unnamed: J4.5, U4.39 (BDBUS1)
unnamed: J4.6, U4.52 (BCBUS1)
unnamed: J4.7, U4.40 (BDBUS2)
unnamed: J4.8, U4.53 (BCBUS2)
unnamed: J4.9, U4.41 (BDBUS3)
unnamed: J4.10, U4.54 (BCBUS3)
unnamed: J4.11, U4.43 (BDBUS4)
unnamed: J4.12, U4.55 (BCBUS4)
unnamed: J4.13, U4.44 (BDBUS5)
unnamed: J4.14, U4.57 (BCBUS5)
unnamed: J4.15, U4.45 (BDBUS6)
unnamed: J4.16, U4.58 (BCBUS6)
unnamed: J4.17, U4.46 (BDBUS7)
unnamed: J4.18, U4.59 (BCBUS7)
unnamed: JP1.1, Y2.3 (OUT)
unnamed: R8.2, U2.1 (DO)
unnamed: R9.1, U4.14 (~RESET)
unnamed: R10.1, U4.6 (REF)
USB_D+: J1.3 (D+), U4.8 (DP)
USB_D-: J1.2 (D-), U4.7 (DM)

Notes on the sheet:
Waveform Generator
4/5/2017

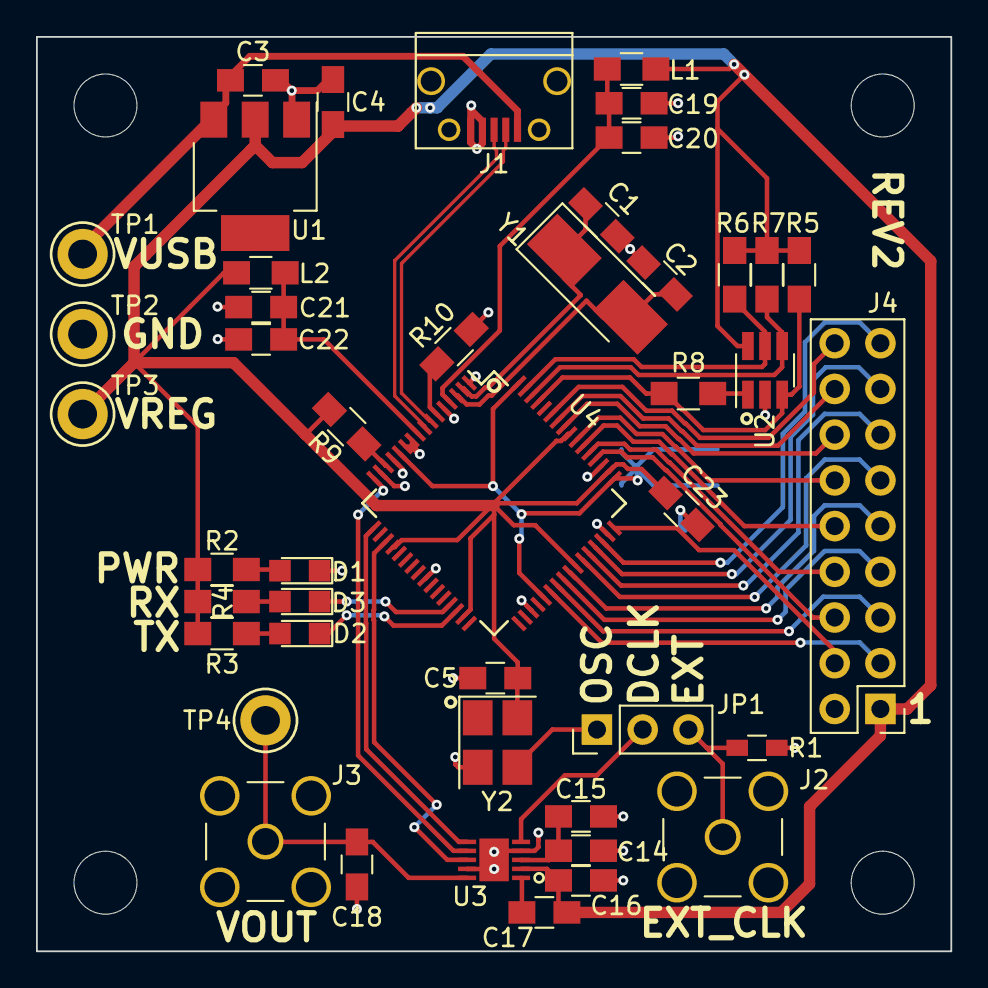
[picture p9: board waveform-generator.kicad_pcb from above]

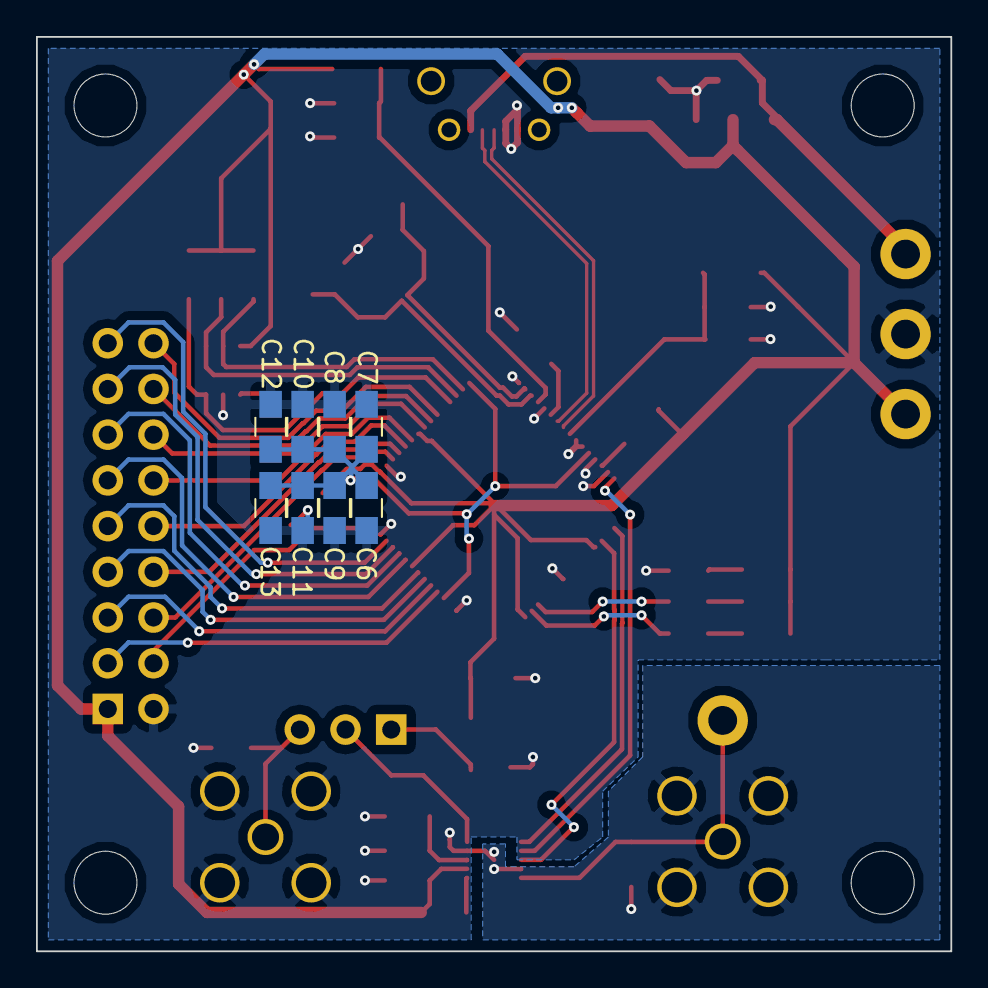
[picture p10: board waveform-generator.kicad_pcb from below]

Board: 2 copper layers, 50.8 x 50.8 mm, 53 parts (8 on the bottom side), 46 nets.

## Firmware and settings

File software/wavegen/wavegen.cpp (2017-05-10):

/* wavegen.cpp
 * Copyright (C) 2017 Tim Prince
 *
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
 * You should have received a copy of the GNU General Public License
 * along with this program.  If not, see <http://www.gnu.org/licenses/>.
 */

#include "wavegen.h"

#include <cstdlib>
#include <cstring>
#include <memory>
#include <sstream>
#include <type_traits>
#include <utility>

#include "ad9837.h"
#include "exceptions.h"
#include "packet.h"
#include "util.h"

namespace wavegen {

namespace {
    constexpr int vid = 0x0403;
    constexpr int pid = 0x6010;
    ftdi::endpoint getEndpoint(const std::string& serial = "") {
        return ftdi::endpoint {
            vid, pid,
            /*mfg*/ "", /*desc*/ "USB Function Generator",
            serial
        };
    }
} /* namespace */

device::device(const std::string& serial) :
    spi { ftdi::spi::pins::adbus3, getEndpoint(serial) },
    mclk_freq { ad9837::default_mclk_freq }
{
    initDac();
}

device::~device() noexcept(true)
{
}

device::device(device&& o) noexcept(true) :
    spi { std::move(o.spi) },
    mclk_freq { o.mclk_freq }
{
}

device& device::operator=(device&& o) noexcept(true) {
    std::swap(o.spi, spi);
    mclk_freq = o.mclk_freq;
    return *this;
}

void device::setClockFrequency(uint32_t freq)
{
    mclk_freq = freq;
}

void device::setFrequency(channel_id channel, uint32_t freq)
{
    if (freq >= ad9837::default_mclk_freq) {
        throw error(WHEN("unsupported frequency"));
    }
    uint16_t freg_hi;
    uint16_t freg_lo;
    ad9837::compute_freg(freq, mclk_freq, freg_hi, freg_lo);

    uint16_t reg_mask = (channel == 0) ?
        ad9837::reg_mask::freq0 :
        ad9837::reg_mask::freq1 ;

    freg_hi |= reg_mask;
    freg_lo |= reg_mask;

    spi.transmit({byteswap(freg_lo)});
    spi.transmit({byteswap(freg_hi)});
}

void device::setPhase(channel_id channel, uint16_t phase)
{
    if (phase & ~mask(12U)) {
        throw error(WHEN("unsupported phase"));
    }
    uint16_t data = (channel == 0) ?
        ad9837::reg_mask::phase0 :
        ad9837::reg_mask::phase1 ;

    data |= phase;
    spi.transmit({byteswap(data)});
}

void device::setOutput(channel_id channel, output_waveform type)
{
    using namespace ad9837;
    uint16_t command = reg_mask::control;
    command |= ctrl_bits::b28;

    if (channel == 1) {
        command |= ctrl_bits::fsel;
        command |= ctrl_bits::psel;
    }

    switch (type) {
    case output_waveform::sinusoid:
        break;
    case output_waveform::triangle:
        command |= ctrl_bits::mode;
        break;
    case output_waveform::square:
        command |= ctrl_bits::opbiten;
	command |= ctrl_bits::div2;
        break;
    }

    spi.transmit({byteswap(command)});
}

void device::initDac()
{
    packet ctrl_reset = {
        uint8_t(0b00100001),
        uint8_t(0b00000000)
    };

    spi.transmit(ctrl_reset);
    setFrequency(0, 0);
    setFrequency(1, 0);
    setPhase(0, 0);
    setPhase(1, 0);

    setOutput(0);
}

} /* namespace wavegen */

std::vector<std::string> wavegen::enumerateDevices()
{
    auto endpoints = ftdi::getAvailableEndpoints(vid, pid);
    std::vector<std::string> result;
    result.reserve(endpoints.size());

    ftdi::endpoint expected = getEndpoint();

    for (const auto& ep : endpoints) {
        if (ep.match(expected)) {
            result.push_back(ep.serial);
        }
    }
    return result;
}

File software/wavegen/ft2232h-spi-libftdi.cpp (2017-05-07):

/* ft2232h-spi-libftdi.cpp
 * Copyright (C) 2017 Tim Prince
 *
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
 * You should have received a copy of the GNU General Public License
 * along with this program.  If not, see <http://www.gnu.org/licenses/>.
 */

#include "ft2232h-spi.h"

#include <sstream>
#include <ftdi.h>

#include "packet.h"
#include "util.h"

namespace wavegen {
namespace ftdi {

namespace {

ftdi_context *getContext()
{
    static std::unique_ptr<ftdi_context, decltype(&ftdi_free)> global_ctxt
    { nullptr, &ftdi_free };
    if (!global_ctxt) {
        global_ctxt = { ftdi_new(), &ftdi_free };
    }

    return global_ctxt.get();
}

constexpr uint16_t spi_clkdiv = 0x05db; /* 1 MHz */
constexpr uint8_t bad_opcode_reply = 0xfa;
}

struct spi::impl
{
    impl(pins cs_pin) :
        ctxt(getContext()),
        cs_pin(cs_pin)
    {
    }

    packet csPacket(bool cs_high);
    void init(const endpoint& ep);
    void sendRaw(const packet& p);
    void sync();
    void expectResponse(const packet& p);
    void expectEmptyResponse();
    void onError(const std::string& when);

    struct ftdi_context *ctxt;
    pins cs_pin;
};

spi::~spi()
{
}

spi::spi(
    pins cs, const endpoint& ep)
    noexcept(false) :
    d(new impl { cs })
{
    d->init(ep);
}

spi::spi(spi&& other) noexcept(true)
    : d(std::move(other.d))
{
}

spi& spi::operator=(spi&& other) noexcept(true)
{
    std::swap(d, other.d);
    return *this;
}

void spi::transmit(const packet& payload)
{
    if (payload.size < 1) {
        throw error(WHEN("can't send a packet with <1 bytes."));
    }

    packet p;
    p.append(d->csPacket(false));
    p.append({ opcodes::write, uint16_t(payload.size - 1) });
    p.append(payload);
    p.append(d->csPacket(true));
    d->sendRaw(p);
    d->expectEmptyResponse();
}

void spi::impl::sendRaw(const packet& p)
{
    if (ftdi_write_data(ctxt, const_cast<uint8_t*>(p.buffer), p.size) != p.size) {
        onError(WHEN("ftdi_write_data"));
    }
}

packet spi::impl::csPacket(bool cs_high)
{
    uint8_t pin_state =
        spi::pins::sck |
        (cs_high ? cs_pin : 0);
    return {
        opcodes::set_low_bits,
        pin_state,
        uint8_t(pins::sck | pins::sdata | cs_pin)
    };
}

void spi::impl::init(const endpoint& ep)
{
    if (ftdi_set_interface(ctxt, INTERFACE_A)) {
        onError(WHEN("ftdi_set_interface"));
    }

    auto descr = ep.description.empty() ? nullptr : ep.description.c_str();
    auto serial = ep.serial.empty() ? nullptr : ep.serial.c_str();

    if (ftdi_usb_open_desc(ctxt, ep.vid, ep.pid, descr, serial)) {
        onError(WHEN("ftdi_usb_open_desc"));
    }

    if (ftdi_set_bitmode(ctxt, 0, BITMODE_RESET)) {
        onError(WHEN("ftdi_set_bitmode"));
    }

    if (ftdi_set_bitmode(ctxt, 0, BITMODE_MPSSE)) {
        onError(WHEN("ftdi_set_bitmode"));
    }

    sync();

    /* Set up basic parameters. */
    sendRaw({
        opcodes::clkdiv_5_enable,
        opcodes::adaptive_clk_disable,
        opcodes::three_phase_disable
    });

    /* Set the baudrate. */
    sendRaw({
        opcodes::set_clkdiv, spi_clkdiv
    });

    /* Configure pin states. */
    sendRaw(csPacket(true));
    sendRaw({
        opcodes::set_high_bits,
        uint8_t(0),
        uint8_t(0)
    });
    expectEmptyResponse();
}

void spi::impl::sync()
{
    uint8_t buffer[2];
    sendRaw(opcodes::loopback_enable);
    expectEmptyResponse();

    sendRaw(opcodes::bogus);

    expectResponse({
        bad_opcode_reply,
        opcodes::bogus,
    });
    expectEmptyResponse();

    sendRaw(opcodes::loopback_disable);
}

void spi::impl::expectResponse(const packet& p)
{
    uint8_t buffer[p.size];
    int rc = ftdi_read_data(ctxt, buffer, p.size);
    if (rc != p.size) {
        std::ostringstream what;
        what << WHEN()
             << "expected " << p.size << " byte reply but got "
             << rc << " bytes.";
        onError(what.str());
    }

    if (memcmp(p.buffer, buffer, p.size) != 0) {
        onError(WHEN("did not receive expected reply"));
    }
}

void spi::impl::expectEmptyResponse()
{
    expectResponse(packet {});
}

void spi::impl::onError(const std::string& when)
{
    throw error(when + ": " + ftdi_get_error_string(ctxt));
}

} /* namespace ftdi */

std::vector<ftdi::endpoint> ftdi::getAvailableEndpoints(int vid, int pid)
{
    auto ctxt = getContext();
    ftdi_device_list *devlist = nullptr;
    auto rc = ftdi_usb_find_all(ctxt, &devlist, vid, pid);

    if (rc < 0) {
        throw ftdi::error {
            std::string { WHEN("getAvailableEndpoints: ") } + ftdi_get_error_string(ctxt)
        };
    }

    scope_guard guard { [devlist]() { ftdi_list_free2(devlist); } };

    std::vector<ftdi::endpoint> result;
    result.reserve(rc);

    std::array<char, 32> mfg_buff;
    std::array<char, 32> descr_buff;
    std::array<char, 32> serial_buff;

    auto curr_dev = devlist;
    for (int i = 0; i < rc; ++i, curr_dev = curr_dev->next) {
        if (ftdi_usb_get_strings(
            ctxt, curr_dev->dev,
            mfg_buff.data(), mfg_buff.size(),
            descr_buff.data(), descr_buff.size(),
            serial_buff.data(), serial_buff.size()))
        {
            throw ftdi::error {
                std::string { WHEN("ftdi_usb_get_strings2: ") } + ftdi_get_error_string(ctxt)
            };
        }

        result.emplace_back(
            vid, pid,
            std::string { mfg_buff.data() },
            std::string { descr_buff.data() },
            std::string { serial_buff.data() }
        );
    }
    return result;
}

} /* namespace wavegen */

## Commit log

2017-04-07 Initial commit.
    [waveform-generator.kicad_pcb, waveform-generator.sch, wavegen-alt.kicad_pcb]
2017-04-08 Replace slots with holes.
    [waveform-generator.kicad_pcb]
2017-04-08 Add gerbers.
    [waveform-generator-B.Cu.gbl, waveform-generator-B.Mask.gbs, waveform-generator-B.SilkS.gbo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]
2017-04-10 Fixup analog-digital ground connection.
    [waveform-generator.kicad_pcb]
2017-04-17 Add prototype control software.
    [waveform-generator-B.Cu.gbl, waveform-generator-B.Mask.gbs, waveform-generator-B.SilkS.gbo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]
2017-04-18 Add orientation marks to silkscreen.
    [waveform-generator.kicad_pcb]
2017-04-19 Fixes for GCC 4.9 compatibility.
    [wavegen.cpp]
2017-04-19 Add design files for the rev1 hardware.
    [waveform-generator-B.Cu.gbl, waveform-generator-B.Mask.gbs, waveform-generator-B.SilkS.gbo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]
2017-04-19 Remove source from gh-pages branch.
    [waveform-generator-B.Cu.gbl, waveform-generator-B.Mask.gbs, waveform-generator-B.SilkS.gbo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]
2017-04-21 Refactor FTDI-specific logic to allow swapping out driver libraries.
    [ft2232h-spi-libftdi.cpp, wavegen.cpp]
2017-04-21 Add stub for D2XX-based SPI.
2017-04-21 Get stuff building with visual studio, implement LibMPSSE-SPI wrapper.
2017-04-22 Initial rev3 work.
    [Connectors.sch, FTDI.sch, FTDI_EEPROM.sch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]
2017-04-23 Add AD9102 to the schematic.
    [Connectors.sch, FTDI.sch, analog.sch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]
2017-04-24 Add initial output amplifier design.
    [Connectors.sch, FTDI.sch, analog.sch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]
2017-04-24 Add bypass caps to output amp.
    Fixes #4.
    [analog.sch]
2017-04-26 Add an additional output stage to the amplifier sim.
2017-04-26 Fixup the fab layers to make component values visible.
    [waveform-generator.kicad_pcb]
2017-04-28 Finish up output amp schematic.
    [Connectors.sch, FTDI.sch, analog.sch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]
2017-04-28 Add missing footprints.
    [Connectors.sch, FTDI.sch, analog.sch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]
2017-04-28 Make some progress on layout.
    [power.sch, rev3.kicad_pcb]
2017-04-29 Fix incorrect connection to output amp.
    [analog.sch]
2017-04-29 Add 3.2x2.5 oscillator footprint
2017-04-29 Add decoupling to biasing amp.
    [analog.sch]
2017-04-29 Fixup USB footprint shield pin.
2017-04-29 Fixup vreg decoupling.
    [power.sch]
2017-04-29 Initial placement.
    [rev3.kicad_pcb]
2017-04-29 First routing attempt.
    [analog.sch, rev3.kicad_pcb]
2017-04-29 Update component selection based on digikey availability.
    [analog.sch, bom.xlsx, power.sch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]
2017-04-29 Continue iterating on layout.
    [rev3.kicad_pcb]
2017-05-02 Initial attempt at a complete layout.
    [analog.sch, rev3.kicad_pcb]
2017-05-02 Final touches.
    [rev3.kicad_pcb]
2017-05-02 Generate gerbers.
    [rev3-B.Cu.gbl, rev3-B.Mask.gbs, rev3-B.SilkS.gbo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]
2017-05-02 Add a script to make the gerbers Seeedstudio-friendly.
2017-05-07 Move OSHW logo. Add github link.
    [rev3.kicad_pcb]
2017-05-07 Add BOM for rev2.
    [bom.xlsx]
2017-05-07 Add ability to filter devices by serial.
2017-05-07 Rework how we get the git revision.
    [wavegen.cpp]
2017-05-07 Refactor device::setOutput
2017-05-07 Allow for multiple connected devices.
2017-05-10 Output the correct frequency for square waves.
    Fixes #1.
    [wavegen.cpp]

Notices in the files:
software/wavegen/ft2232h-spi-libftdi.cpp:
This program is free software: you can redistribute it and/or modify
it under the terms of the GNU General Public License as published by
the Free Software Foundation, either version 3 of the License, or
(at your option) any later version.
